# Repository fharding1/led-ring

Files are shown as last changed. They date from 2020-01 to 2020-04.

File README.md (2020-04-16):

# LED Ring

A bright voltage regulated LED ring for vision tracking in FRC.

Copyright Franklin Harding 2020.

This source describes Open Hardware and is licensed under the CERN-OHL-Pv2

You may redistribute and modify this documentation and make products using it under the terms of the CERN-OHL-P v2 (https:/cern.ch/cern-ohl).This documentation is distributed WITHOUT ANY EXPRESS OR IMPLIED WARRANTY, INCLUDING OF MERCHANTABILITY, SATISFACTORY QUALITY AND FITNESS FOR A PARTICULAR PURPOSE. Please see the CERN-OHL-P v2 for applicable conditions

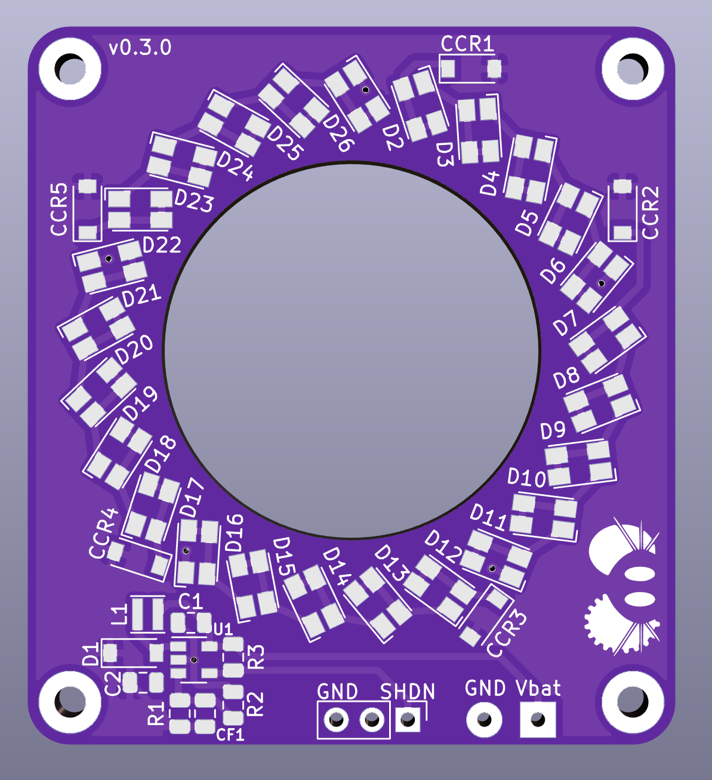
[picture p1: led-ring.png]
LED Ring


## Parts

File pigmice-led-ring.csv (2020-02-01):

Ref | Value | Part | Footprint | Description | Manufacturer | Manufacturer Part Number | Digi-Key Part Number | Quantity
C1 | 2.2uF | Device:C | Capacitor_SMD:C_0805_2012Metric | Unpolarized capacitor | taiyo-yuden | EMK212BJ225KG-T | 587-1293-1-ND | 1
C2 | 4.7uF | Device:C | Capacitor_SMD:C_0805_2012Metric | Unpolarized capacitor | taiyo-yuden | EMK212ABJ475KG-T | 587-5838-1-ND | 1
CCR1-5 | 25mA | Device:D_Small | Diode_SMD:D_SOD-123 | Diode, small symbol | on-semiconductor | NSI45025AT1G | NSI45025AT1GOSCT-ND | 5
CF1 | 330pF | Device:C | Capacitor_SMD:C_0805_2012Metric | Unpolarized capacitor | yageo | CC0805KRX7R9BB331 | 311-1192-1-ND | 1
D1 | D_Schottky | Device:D_Schottky | Diode_SMD:D_SOD-123 | Schottky diode | on-semiconductor | MBR0520LT1G | MBR0520LT1GOSCT-ND | 1
D2-26 | LED | Device:LED_Small | led-ring:LED_Avago_PLCC4_3.2x2.8mm_CW | Light emitting diode, small symbol | broadcom-limited | ASMT-SGB5-NW703 | 516-3483-1-ND | 25
J2 | Conn_01x03_Female | Connector:Conn_01x03_Female | Connector_PinHeader_2.54mm:PinHeader_1x03_P2.54mm_Vertical | Generic connector, single row, 01x03, script generated (kicad-library-utils/schlib/autogen/connector/) | sullins-connector-solutions | PPPC031LFBN-RC | S7036-ND | 1
L1 | 10uH | Device:L | Inductor_SMD:L_Taiyo-Yuden_NR-24xx | Inductor | taiyo-yuden | NRH2410T100MN | 587-2384-1-ND | 1
R1 | 203k | Device:R | Resistor_SMD:R_0805_2012Metric | Resistor | vishay-thin-film | PTN0805E2033BST1 | 764-1497-1-ND | 1
R2 | 13.3k | Device:R | Resistor_SMD:R_0805_2012Metric | Resistor | yageo | RC0805FR-0713K3L | 311-13.3KCRCT-ND | 1
R3 | 47k | Device:R_Small | Resistor_SMD:R_0805_2012Metric | Resistor, small symbol | Te-connectivity-passive-product | CRGCQ0805J47K | A130144CT-ND | 1
U1 | LMR62014XMF | Regulator_Switching:LMR62014XMF | Package_TO_SOT_SMD:SOT-23-5 | 1.4A, 20Vout Step-Up Voltage Regulator, 1.6MHz Frequency, SOT-23-5 | texas-instruments | LMR62014XMFE-NOPB | LMR62014XMFE/NOPBCT-ND | 1

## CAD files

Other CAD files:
Connectors_Anderson.pretty-master/housing.scad
Connectors_Anderson.pretty-master/45A-VERT-PAIR.blend

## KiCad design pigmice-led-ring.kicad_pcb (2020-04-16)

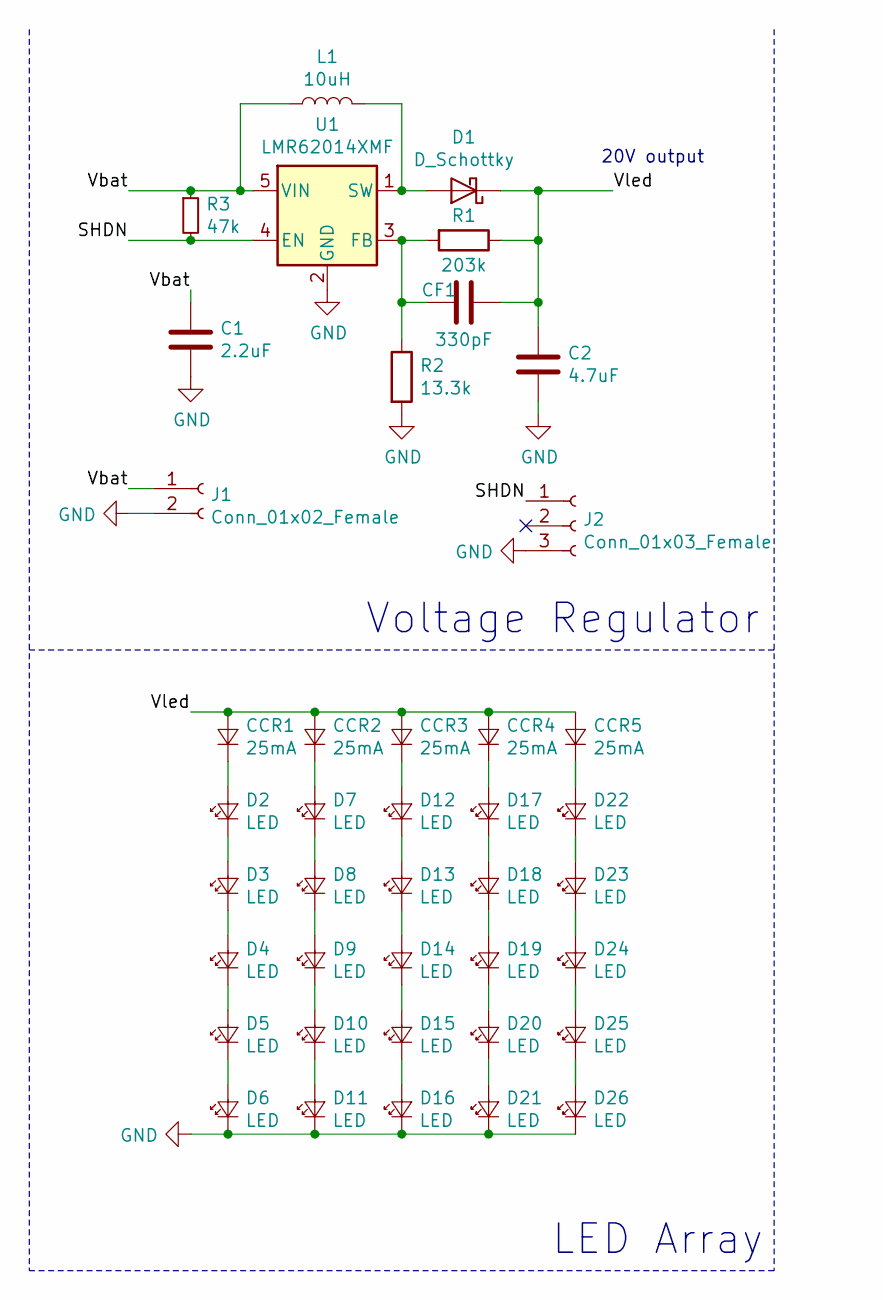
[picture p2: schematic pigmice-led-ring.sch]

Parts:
C1: 2.2uF; C_0805_2012Metric
C2: 4.7uF; C_0805_2012Metric
CCR1, CCR2, CCR3, CCR4, CCR5: 25mA; D_SOD-123
CF1: 330pF; C_0805_2012Metric
D1: D_Schottky; D_SOD-123
D2, D3, D4, D5, D6, D7, D8, D9, D10, D11, D12, D13, D14, D15, D16, D17, D18, D19, D20, D21, D22, D23, D24, D25, D26: LED; LED_Avago_PLCC4_3.2x2.8mm_CW
J1: Conn_01x02_Female; 45A-VERT-PAIR
J2: Conn_01x03_Female; PinHeader_1x03_P2.54mm_Vertical
L1: 10uH; L_Taiyo-Yuden_NR-24xx
R1: 203k; R_0805_2012Metric
R2: 13.3k; R_0805_2012Metric
R3: 47k; R_0805_2012Metric
U1: LMR62014XMF; SOT-23-5

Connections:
/SHDN: J2.1, R3.2, U1.4 (EN)
/Vbat: C1.1, J1.1, L1.1, R3.1, U1.5 (VIN)
/Vled: C2.1, CCR1.2 (A), CCR2.2 (A), CCR3.2 (A), CCR4.2 (A), CCR5.2 (A), CF1.2, D1.1 (K), R1.1
GND: C1.2, C2.2, D6.1 (K), D11.1 (K), D16.1 (K), D21.1 (K), D26.1 (K), J1.2, J2.3, R2.2, U1.2 (GND)
unnamed: CCR1.1 (K), D2.2 (A)
unnamed: CCR2.1 (K), D7.2 (A)
unnamed: CCR3.1 (K), D12.2 (A)
unnamed: CCR4.1 (K), D17.2 (A)
unnamed: CCR5.1 (K), D22.2 (A)
unnamed: CF1.1, R1.2, R2.1, U1.3 (FB)
unnamed: D1.2 (A), L1.2, U1.1 (SW)
unnamed: D2.1 (K), D3.2 (A)
unnamed: D3.1 (K), D4.2 (A)
unnamed: D4.1 (K), D5.2 (A)
unnamed: D5.1 (K), D6.2 (A)
unnamed: D7.1 (K), D8.2 (A)
unnamed: D8.1 (K), D9.2 (A)
unnamed: D10.1 (K), D11.2 (A)
unnamed: D9.1 (K), D10.2 (A)
unnamed: D12.1 (K), D13.2 (A)
unnamed: D13.1 (K), D14.2 (A)
unnamed: D14.1 (K), D15.2 (A)
unnamed: D15.1 (K), D16.2 (A)
unnamed: D17.1 (K), D18.2 (A)
unnamed: D18.1 (K), D19.2 (A)
unnamed: D19.1 (K), D20.2 (A)
unnamed: D20.1 (K), D21.2 (A)
unnamed: D22.1 (K), D23.2 (A)
unnamed: D23.1 (K), D24.2 (A)
unnamed: D24.1 (K), D25.2 (A)
unnamed: D25.1 (K), D26.2 (A)

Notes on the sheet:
20V output
Voltage Regulator
LED Array

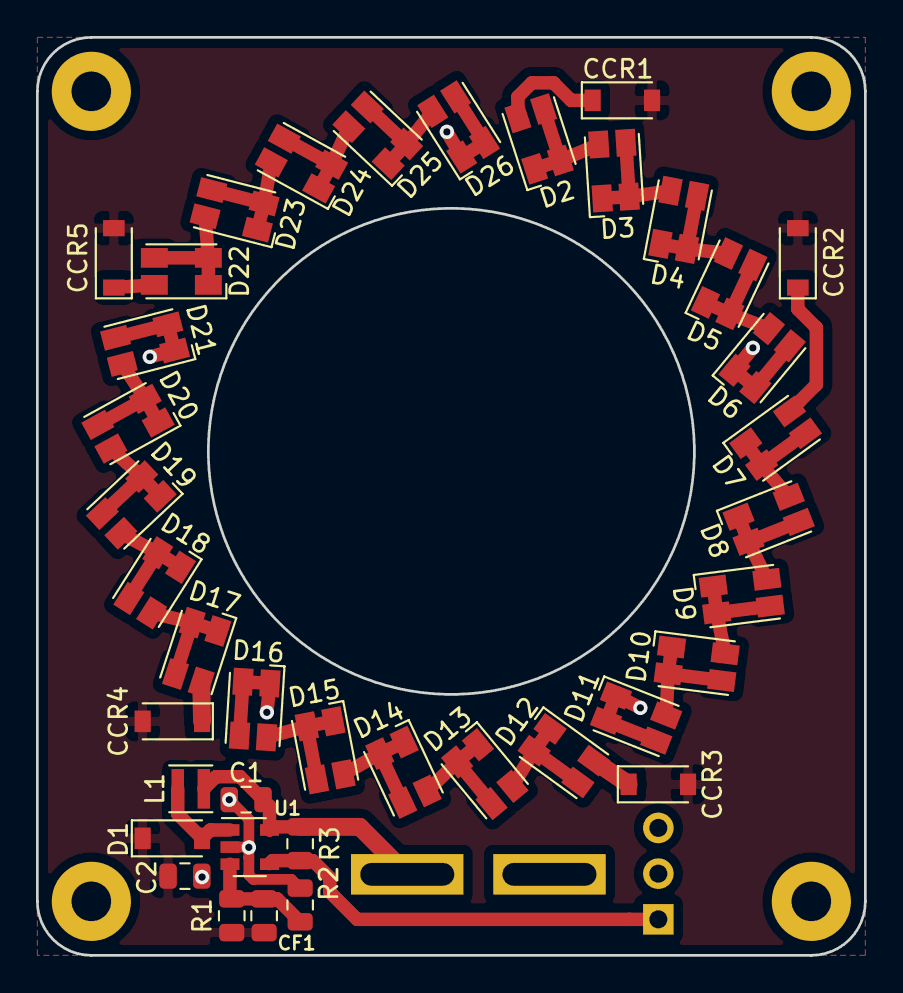
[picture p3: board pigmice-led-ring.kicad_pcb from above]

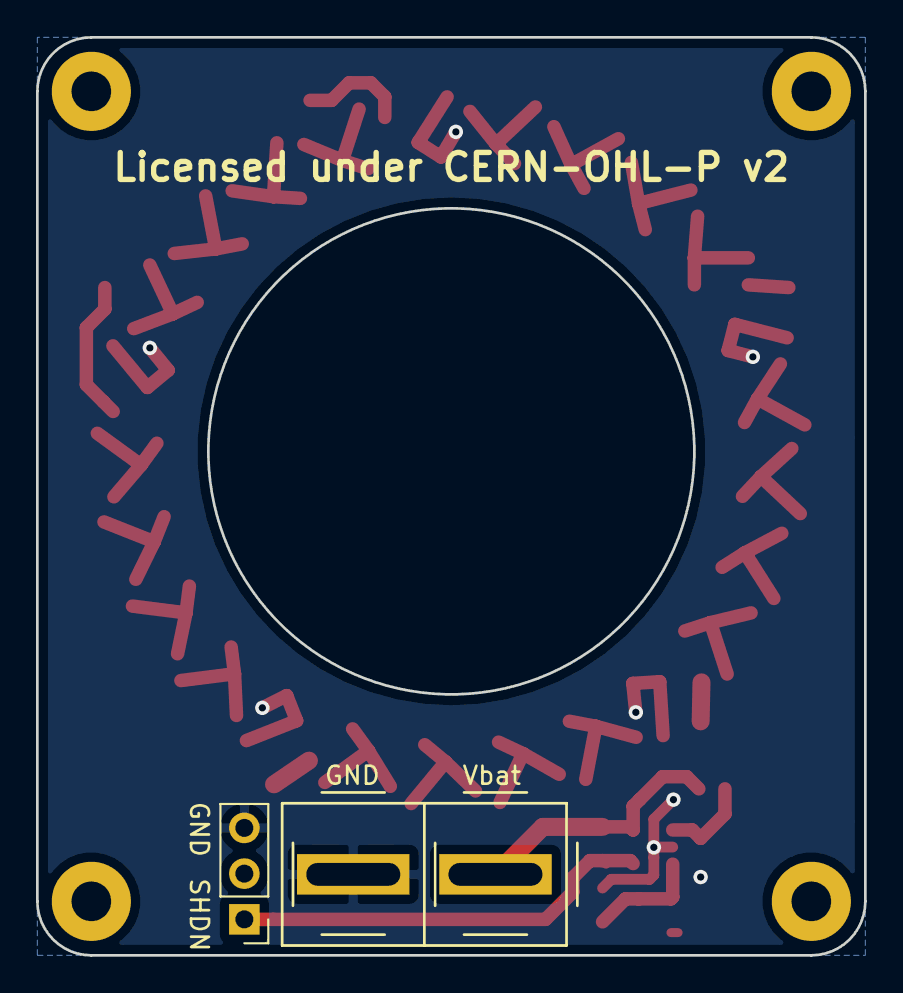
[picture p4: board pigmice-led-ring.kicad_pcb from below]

Board: 2 copper layers, 46.0 x 51.0 mm, 41 parts (2 on the bottom side), 31 nets.

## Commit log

2020-01-08 Initial KiCAD files
    [pigmice-led-ring.kicad_pcb, pigmice-led-ring.sch]
2020-01-08 Add README, 22ohm -> 82ohm
    [pigmice-led-ring.kicad_pcb, pigmice-led-ring.sch]
2020-01-08 Add input voltage and power consumption to README
2020-01-08 Add details for alternative resistors
2020-01-10 rev0.2.0
    * Uses an RCD-24 LED driver for constant current
    * M2 mounting holes
    * Powerpole, PWM connector
    * Sweet graphics :sunglasses:
    [_saved_pigmice-led-ring.sch, pigmice-led-ring.kicad_pcb]
2020-01-14 WIP v0.3.0 work
    [_saved_pigmice-led-ring.sch, pigmice-led-ring.csv, pigmice-led-ring.sch]
2020-01-14 Cleanup voltage regulator circuit spacing
    [pigmice-led-ring.kicad_pcb]
2020-01-14 Add sponsor logos
    [pigmice-led-ring.kicad_pcb]
2020-01-14 Move LED vias out of underneath pad
    [pigmice-led-ring.kicad_pcb]
2020-01-14 Fix R2/CF1 labels
    [pigmice-led-ring.kicad_pcb, pigmice-led-ring.sch]
2020-01-14 Center URS logo better
    [pigmice-led-ring.kicad_pcb]
2020-01-15 Swap out inductor for smaller 2410 footprint
    [pigmice-led-ring.csv, pigmice-led-ring.kicad_pcb, pigmice-led-ring.sch]
2020-01-15 Switch from 150 to 137 ohm resistors for LEDs
    [pigmice-led-ring.csv, pigmice-led-ring.kicad_pcb, pigmice-led-ring.sch]
2020-01-15 Fix LED digikey urls in bom
    [pigmice-led-ring.csv]
2020-01-16 Use CCRs instead of resistors
    [pigmice-led-ring.csv, pigmice-led-ring.kicad_pcb, pigmice-led-ring.sch]
2020-01-16 Move labels a bit
    [pigmice-led-ring.kicad_pcb]
2020-01-16 Remove extraneous trace
    [pigmice-led-ring.kicad_pcb]
2020-01-23 Revision 0.3.1
    - Fixes an issue in the LED footprint resulting in a short between the
    anode and cathode
    - Uses thicker traces where possible
    - Moves CCRs for better connections to Vled plane
    [pigmice-led-ring.kicad_pcb]
2020-01-24 Consolidate BOM
    [pigmice-led-ring.csv]
2020-01-25 Add mini badge
    [pigmice-led-ring.kicad_pcb, pigmice-led-ring.sch]
2020-01-25 Add button to mini-badge
    [pigmice-led-ring.kicad_pcb, pigmice-led-ring.sch]
2020-01-28 Move SHDN and Vbat traces a bit
    [pigmice-led-ring.kicad_pcb]
2020-02-01 Powerpole, DFM, optimize BOM
    * Optimizes BOM to use cheaper components (~$15 components per board)
    * Change power connector to use an Anderson connector
    * Some DFM (remove copper fill logo, center part)
    [45A-VERT-PAIR.blend, housing.scad, pigmice-led-ring.csv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]
2020-02-01 Move over powerpole/PWM connector a bit
    [pigmice-led-ring.kicad_pcb]
2020-02-01 Remove photos, text
    [pigmice-led-ring.kicad_pcb]
2020-04-16 Add CERN OHL v2 permissive license
    [pigmice-led-ring.kicad_pcb]

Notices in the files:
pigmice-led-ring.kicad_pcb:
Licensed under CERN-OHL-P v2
